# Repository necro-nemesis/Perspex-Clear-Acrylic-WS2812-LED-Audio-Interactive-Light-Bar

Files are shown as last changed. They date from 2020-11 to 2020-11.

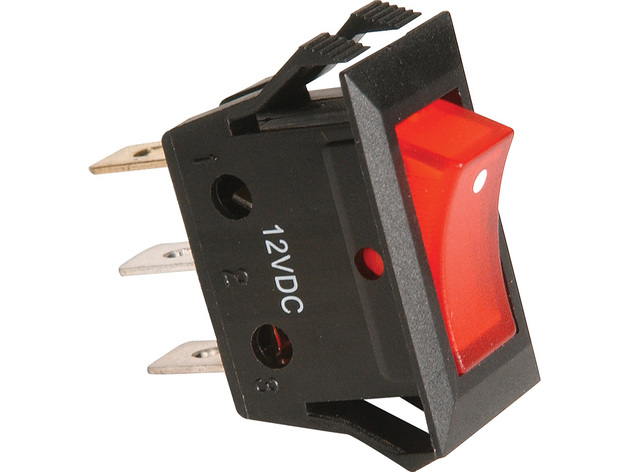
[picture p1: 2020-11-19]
images/rocker_switch.jpg

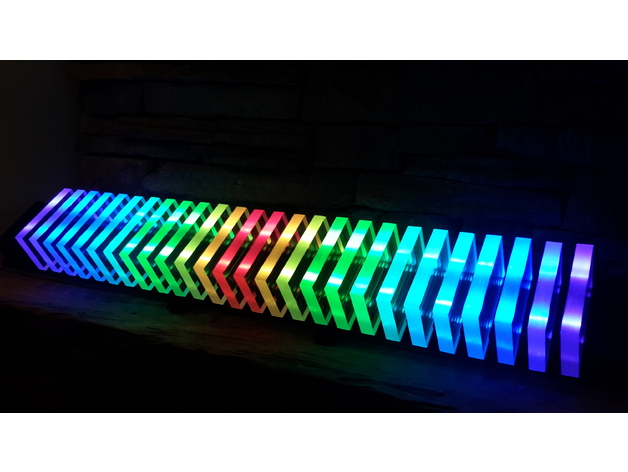
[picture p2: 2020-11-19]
images/20170909_153501.jpg

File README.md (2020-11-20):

# Perspex Clear Acrylic WS2812 LED Audio Interactive Light Bar

Click To View Video (https://youtu.be/7bf3BYers34 "Click to View Video")
### Click on image to view in action. Second sample video at https://youtu.be/d8P9hhyOXbk

# **Summary**

Perspex LED light and sound activated bar

## Material:

- 1 IKEA Moslanda 115cm picture shelf (black)
- 1 Arduino Uno
- 1 Transformer
- 2 1M 30 Pixel/M WS2812 LED strips (total of 52 LEDs required)
- 26 3/4" Thick Perspex Cast Acrylic Blocks 5" x 3"
- 1 MAX9814 Microphone Amplifier Module AGC Auto Gain Control for Arduino
- 1 470 ohm resistor
- 1 10k ohm resistor
- 1 100 uf capaitor
- 1 0.1 uf capacitor
- 1 Rocker Switch Package (L x W x H) 5.0 x 2.8 x 0.8 in. (see images folder)
- 1 Pushbutton Switch Package (L x W x H) 2.4 x 1.4 x 1.2 in. (see images folder)
- 1 48 in. x 3/4 in. x 1/16 in. Aluminum Square Tube
- 10 #8 Pan Head Sheet Metal Screws

## Printables:

- 26 Perspex Mount*
- 8 Led Strip Retainer
- 2 Center Support (minimum 2, additional supports can be added to increase stability across span 6 or 8 recommended)
- 1 Left Angular End
- 1 Right Angular End
- 1 Center Connection Junction
- 1 Arduino Screwless Hobby Top
- 1 Arduino Uno Mountable Bottom

Attention was paid to ensuring all pieces will print without support. There are fine design details to enhance FDM bridging abilities.

*Perspex is cast clear acrylic and as such will vary slightly in thickness. 3 Mount widths are provided to match to the width of your pieces for a snug fit. Before printing you must measure the thickness of each block and print the appropriate width to fit.*

Constructing this is undeniably an undertaking but I never underestimate the maker community's willingness to create astoundingly complex and wonderful things. I posted the entire circuit diagram and sketch to Autodesk Circuit but in my attempt to link it, it appears to have vanished in the move to Tinkercad. If there is enough interest I will recreate it on Tinkercad as well as discuss the assembly process. You will need an accurate means to saw finely cut slots in the IKEA shelf as this forms the basis for mounting and aligning the block retainers. There's a few skills involved but nothing insurmountable. Other than the cuts and soldering, everything else snaps,slides or screws together.





Note the sketch and light bar design uses 13 WS2812 per strip versus the 12 shown in the circuit diagram as this is a limitation of Tinkercad. I have provided a link to the light bar project in Tinkercad. Unfortunately there's problem with Tinckercad running the sketch that ran fine in simulation in previously available Autodesk Circuits and more importantly on a real Arduino Uno. The sketch compiles and runs fine on the real hardware. The signal generator was used for simulation purposes only since the site cannot simulate a MAX9814 but provides input similarly for demonstration.

https://www.tinkercad.com/things/fjsfZ70k4bY

Attribution to Robert Robert on Youtube who provided the design inspiration and original sketch which resulted in this 3d printed version of it and the modified sketch.

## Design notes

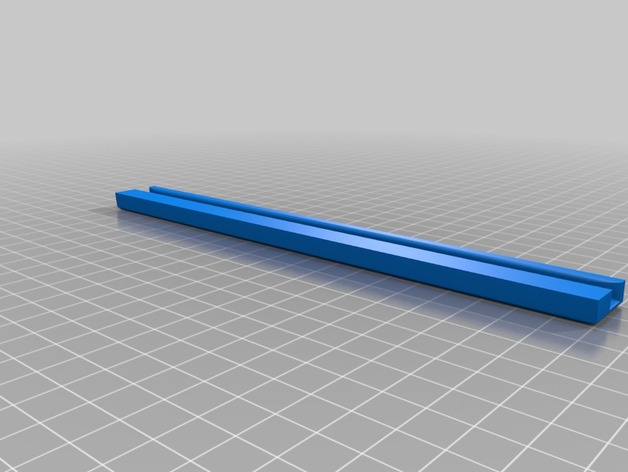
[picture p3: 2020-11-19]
images/e10bdd659c2b4d102f6c60981bce024e.png

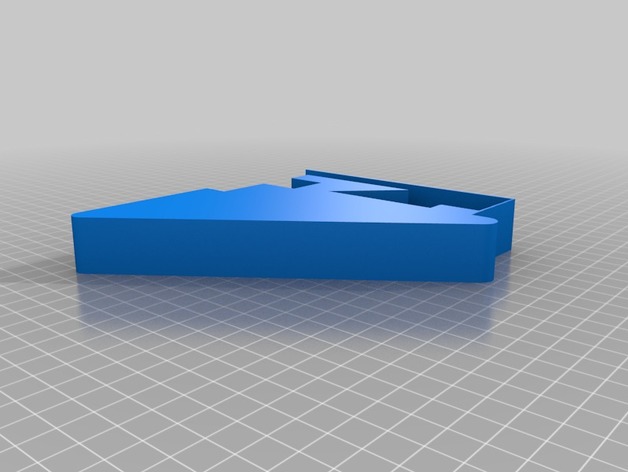
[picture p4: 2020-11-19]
images/a87dbb462eaa0ab76628953a42ff9338.png

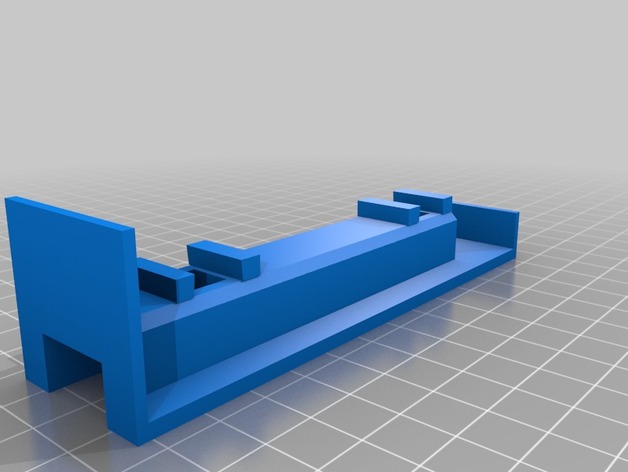
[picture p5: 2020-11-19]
images/7cbe6f95ed668d17131c1e86e14446b0.png

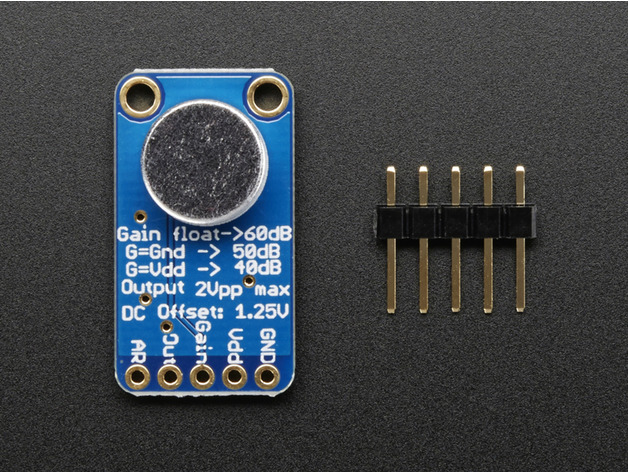
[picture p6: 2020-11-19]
images/MAX9418.jpg

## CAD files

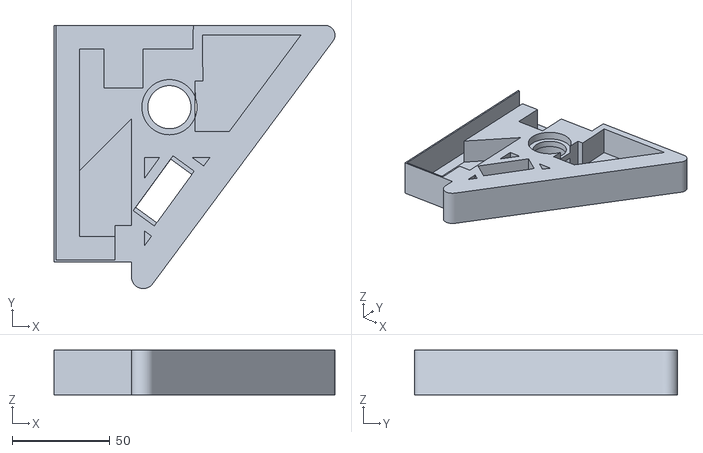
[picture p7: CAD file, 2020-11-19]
Left_Angular_End_Cap_with_Selection_Button_and_OnOff_Swtich.stl
143.7 x 134.6 x 23.0

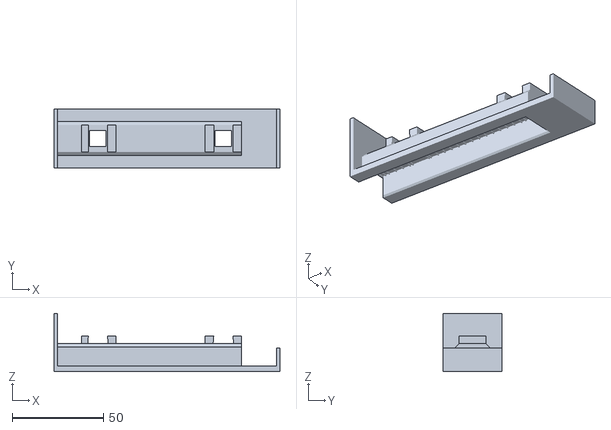
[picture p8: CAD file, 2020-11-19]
Perspex_Mount_17.6mm.stl
124.0 x 32.6 x 32.0

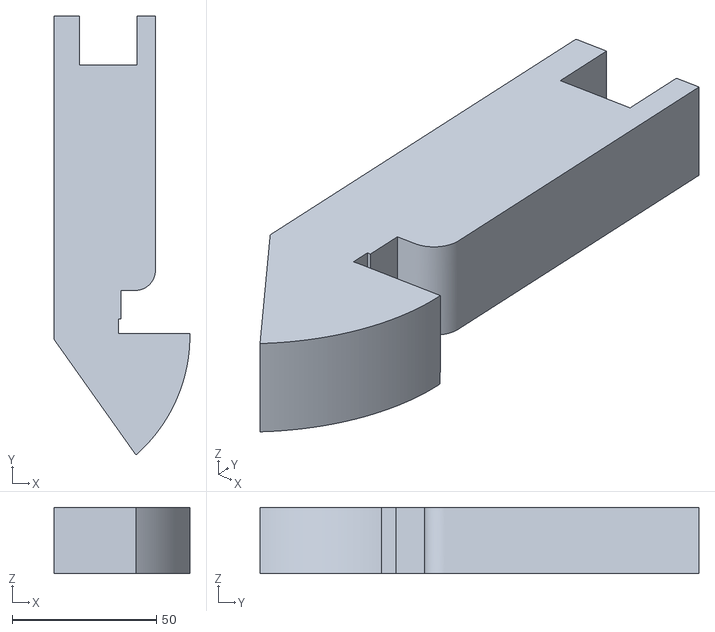
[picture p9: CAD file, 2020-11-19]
Center_Support_feet.stl
47.1 x 152.2 x 23.0

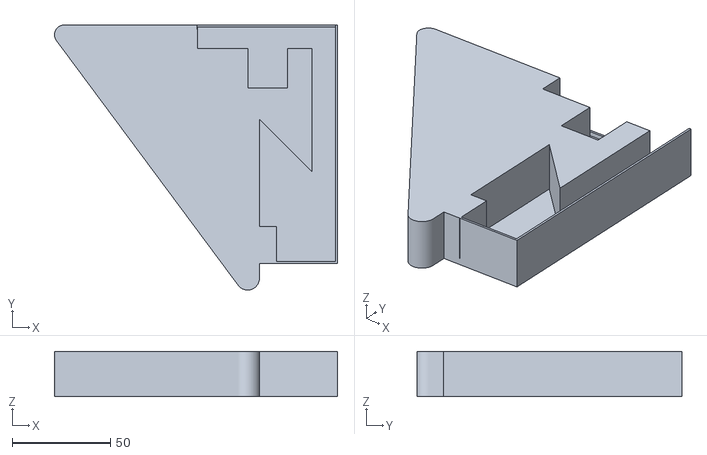
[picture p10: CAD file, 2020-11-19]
Right_Angular_End_Cap.stl
143.7 x 134.6 x 23.0

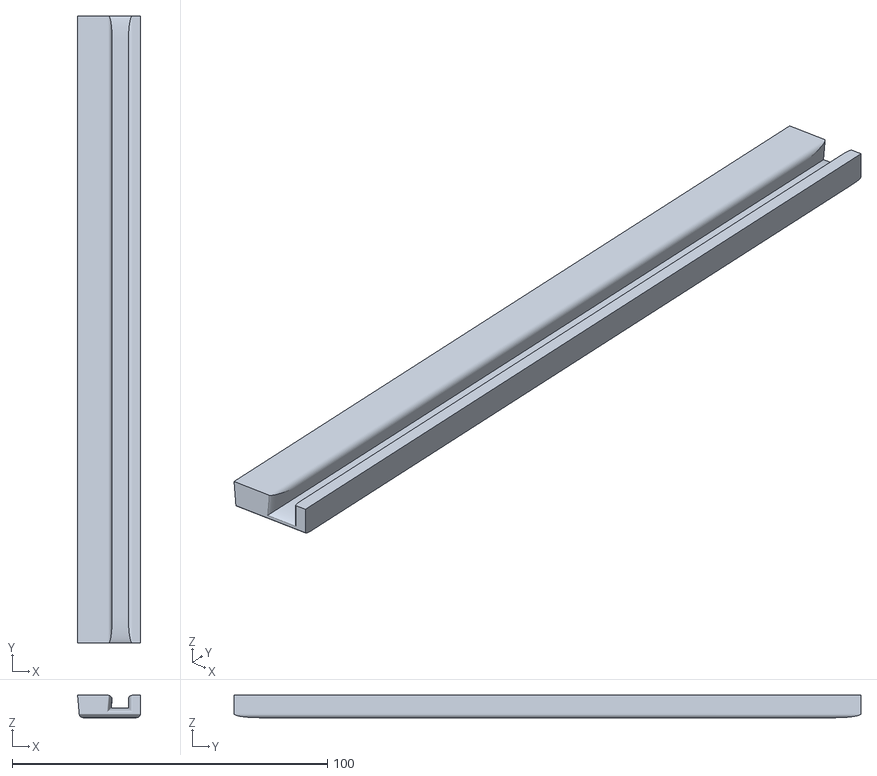
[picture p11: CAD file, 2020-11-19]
Led_Strip_Retainer_and_Interlock_Rail.stl
20.0 x 198.9 x 7.14

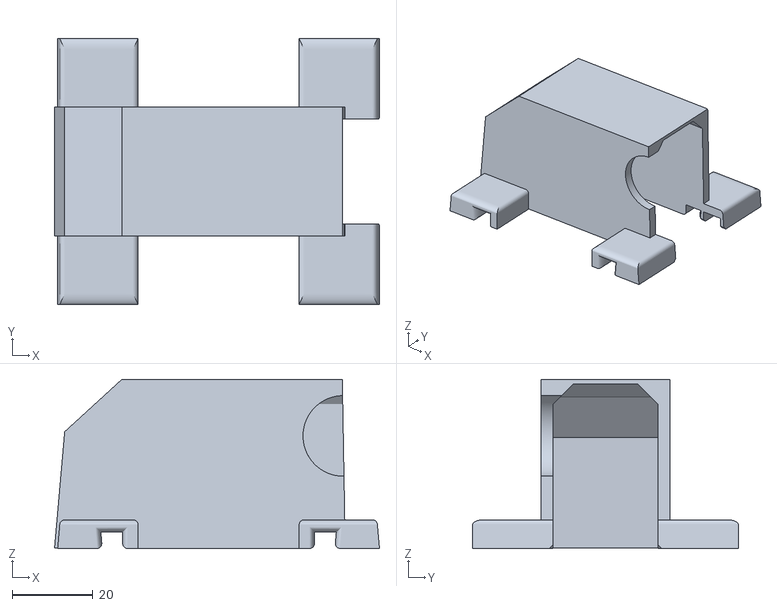
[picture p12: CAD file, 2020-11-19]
Center_Connection_Junction_Housing.stl
80.7 x 66.0 x 42.0

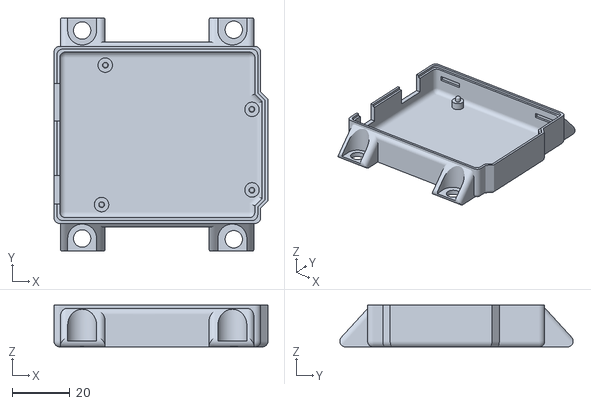
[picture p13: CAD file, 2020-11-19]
Arduino_Screwless_Mountable_Snug_Bottom.stl
74.1 x 80.8 x 14.5

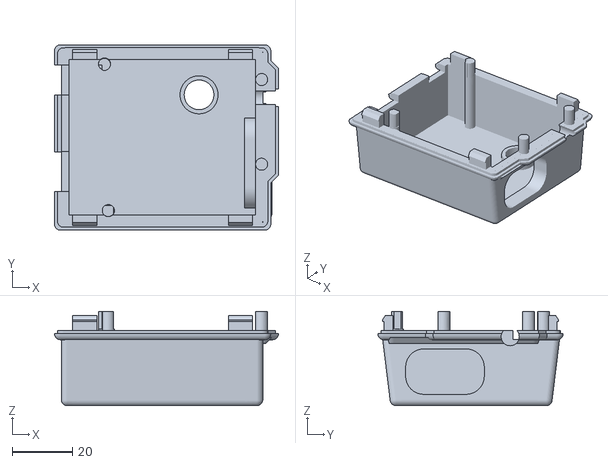
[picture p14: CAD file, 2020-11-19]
Arduino_Screwless_Hobby_Top_w_Microphone_Mount.stl
74.1 x 61.3 x 31.2

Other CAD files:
Perspex_Mount_18.25mm.stl
Perspex_Mount_17.1mm.stl

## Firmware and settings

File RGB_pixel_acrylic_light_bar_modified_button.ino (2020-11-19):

//************
//Sound Level to light show sketch for the
//autogain microphone Amplifier from Adafruit on pin AO
//plus neopixel led functions (pin 6) mapped on to different sound levels to give music to light effects
//
//*************

//lines below set variables for neopixels

#include <Adafruit_NeoPixel.h>
#include <EEPROM.h>

#define NUMBER_PIXEL 15
#define LEDPIN    6

Adafruit_NeoPixel strip = Adafruit_NeoPixel(NUMBER_PIXEL, LEDPIN, NEO_GRB + NEO_KHZ800);

//Global Variables

//Timing Block

int lng = 70;//long delay
int mod = 50;//moderate delay
int sht = 25;//short delay
int hyper = 10;//very short delay
int extreme = 5;//exceedingly short delay

//Misc Variables

uint8_t eepromAddress = 130; //Location to store last mode state during power cycle.
const int sampleWindow = 50; // Sample window width in mS (50 mS = 20Hz)
unsigned int sample;
byte toggleIdle = 1;//Level=0 toggle between idle routines.
int toggleCount = 0;
int pushButton = 2;// Assign pushbutton to input 2.
int modeSelect = 0;// Button routine selection.
boolean buttonState = 0;//
unsigned int spectrumColor[3];
unsigned int pattern [5][3];//Pixel pattern Array 5 rows, 3 RGB values.
boolean UsingBar = false; //Used by Cylon function. Set this to true If you are using the 8x1 Neopixel Bar Or you want to only use 3 leds for the scanner.
unsigned int soundLevel;
unsigned int pixelLength = 1;
unsigned int loudEffect;
unsigned int sound;


//Function Prototypes

void CylonEyeUp(uint32_t Co, uint32_t Ct, uint32_t Ctt, uint8_t Delay, int TotalPixels, int pStart);
void CylonEyeDown(uint32_t Co, uint32_t Ct, uint32_t Ctt, uint8_t Delay, int TotalPixels, int pEnd);
void Seizure(unsigned int flashRate);
void rainbowCycle(uint8_t wait, boolean direction);
void pixelFill(int pixelLength);
void turnBlack();
void colorWipe(uint32_t c, uint8_t wait);
void theaterChase(uint32_t c, uint8_t wait);
void Sparkle(byte red, byte green, byte blue, int SpeedDelay);
int Sample();
void setColor();


void setup()
{
  strip.begin();//initialises neopixels
  strip.setBrightness(255);// set brightness from 0 to max is 255
  strip.show();//clears any previous data in the strip
  pinMode (6, OUTPUT);
  pinMode (pushButton,INPUT);
  Serial.begin(9600);//set up for checking mic is working
}

void loop()
{
  // Select Mode of operation
  modeSelect = EEPROM.read(eepromAddress);
  buttonState = digitalRead(pushButton);
  if (modeSelect>3)
    {
      modeSelect=0;
      EEPROM.write(eepromAddress,modeSelect);
      for (int i = 0; i < 5; i++) {
        CylonEyeUp(strip.Color(175, 0, 0), strip.Color(25, 0, 0), strip.Color(10, 0, 0), hyper, strip.numPixels(), 0);
        //delay(hyper);
        CylonEyeDown(strip.Color(175, 0, 0), strip.Color(25, 0, 0), strip.Color(10, 0, 0), hyper, strip.numPixels(), 0);
        //delay(hyper);
      }//close Cylon;
    }
      else if (buttonState==1)
    {
      modeSelect++;
      EEPROM.write(eepromAddress,modeSelect);
      Seizure(hyper);  
    }
  Serial.print("  mode= ");
  Serial.println(modeSelect);
  switch (modeSelect){
    case 0:
   
  //Mode 0 Audio Light Show.
  //lines below are for the microphone sampling from Adafruit autogain mic
  //open void loop
  //first run the sound sampling




 
  soundLevel=Sample();

  
  //next section is a series of 12 (0-11) 'if' statements which trigger different patterns.
  //it is a combination of a traditional VU style meter fill of the strip
  // combined with randomised animated patterns to keep it interesting
  if (soundLevel > 0)
  {
   toggleIdle = ! toggleIdle;
   toggleCount = 0;
  }
  if (soundLevel == 0)
  {
    //open if 0. When there is silence a rainbow pattern runs
    if (toggleIdle == 0 && toggleCount < 3)
    {
      rainbowCycle(1,1);//from the neopixel library
      toggleCount++;
    }
    if (toggleIdle == 0 && toggleCount >=3)
    {
      rainbowCycle(4,1);
    }
    if (toggleIdle == 1)
    {
      for (int i = 0; i < 1; i++) {
        int x = random(0, 256); int y = random(0, 256); int z = random(0, 256);
        CylonEyeUp(strip.Color(x, y, z), strip.Color(x / 2, y / 2, z / 2), strip.Color(x / 4, y / 4, z / 4), sht, strip.numPixels(), 0);
        CylonEyeDown(strip.Color(x, y, z), strip.Color(x / 2, y / 2, z / 2), strip.Color(x / 4, y / 4, z / 4), sht, strip.numPixels(), 0);
        toggleIdle = ! toggleIdle;
      }
    }
  }//close if 0 statement

  if (soundLevel == 1)
  {
    //open level 1 if statement which contains 5 randomised options

    int level1Color = random(1, 7);//choose random number 1 - 5
    pixelLength = 2;

    if (level1Color == 1) //if random no 1 choses show
    {
      pattern[0][0] = 0; pattern[0][1] = 255; pattern[0][1] = 255;
      pixelFill(pixelLength);
    }//close random no. 1

    else if (level1Color == 2) //if random no 2 choses show green
    {
      pattern[0][0] = 0; pattern[0][1] = 255; pattern[0][1] = 0;
      pixelFill(pixelLength);
    }//close green

    else if (level1Color == 3) //run blue
    {
      pattern[0][0] = 0; pattern[0][1] = 0; pattern[0][1] = 255;
      pixelFill(pixelLength);
    }//close blue

    else if (level1Color == 4) //run yellow
    {
      pattern[0][0] = 255; pattern[0][1] = 255; pattern[0][1] = 0;
      pixelFill(pixelLength);
    }//close yellow

    else if (level1Color == 5) //run Cylon red
    { //Cylon loop
      for (int i = 0; i < 1; i++) {
        CylonEyeUp(strip.Color(175, 0, 0), strip.Color(25, 0, 0), strip.Color(10, 0, 0), sht, strip.numPixels(), 0);
        delay(sht);
        CylonEyeDown(strip.Color(175, 0, 0), strip.Color(25, 0, 0), strip.Color(10, 0, 0), sht, strip.numPixels(), 0);
        delay(sht);
        CylonEyeUp(strip.Color(random(0, 256), random(0, 256), random(0, 256)), strip.Color(0, 0, 0), strip.Color(0, 0, 0), hyper, strip.numPixels(), 0);
      }//close Cylon
    }//close red

    else if (level1Color == 6) //turn black
    {
      turnBlack();
    }
  }//end of if sound level 1 options


  if (soundLevel == 2)
  {
    //open level 2

    int level2Color = random(1, 7);//choose one of 5 options if sound level 2
    pixelLength = 3;
    if (level2Color == 1) //run red mix
    {

      strip.setPixelColor(0, 255, 0, 0);
      strip.setPixelColor(1, 0, 0, 255);
      strip.setPixelColor(2, 255, 0, 0);
      strip.setPixelColor(3, 0, 0, 0);
      strip.setPixelColor(4, 0, 0, 0);
      strip.setPixelColor(5, 0, 0, 0);
      strip.setPixelColor(6, 0, 0, 0);
      strip.setPixelColor(7, 0, 0, 0);
      strip.setPixelColor(8, 0, 0, 0);
      strip.setPixelColor(9, 0, 0, 0);
      strip.setPixelColor(10, 0, 0, 0);
      strip.setPixelColor(11, 0, 0, 0);
      strip.setPixelColor(12, 0, 0, 0);
      strip.setPixelColor(13, 0, 0, 0);
      strip.setPixelColor(14, 0, 0, 0);
      strip.show();
      delay(lng);
    }//close option 1 red

    else if (level2Color == 2) //run green mix
    {
      //open option 2
      pattern[0][0] = 0; pattern[0][1] = 206; pattern[0][1] = 209;
      pixelFill(pixelLength);
    }//close green

    else if (level2Color == 3) //run blue mix
    {
      //open option 3

      strip.setPixelColor(0, 0, 0, 255);
      strip.setPixelColor(1, 255, 0, 0);
      strip.setPixelColor(2, 0, 0, 255);
      strip.setPixelColor(3, 0, 0, 0);
      strip.setPixelColor(4, 0, 0, 0);
      strip.setPixelColor(5, 0, 0, 0);
      strip.setPixelColor(6, 0, 0, 0);
      strip.setPixelColor(7, 0, 0, 0);
      strip.setPixelColor(8, 0, 0, 0);
      strip.setPixelColor(9, 0, 0, 0);
      strip.setPixelColor(10, 0, 0, 0);
      strip.setPixelColor(11, 0, 0, 0);
      strip.setPixelColor(12, 0, 0, 0);
      strip.setPixelColor(13, 0, 0, 0);
      strip.setPixelColor(14, 0, 0, 0);
      strip.show();
      delay(lng);
    }//close option 3 blue

    else if (level2Color == 4) //run yellow
    {
      //open option 4
      pattern[0][0] = 255; pattern[0][1] = 255; pattern[0][1] = 0;
      pixelFill(pixelLength);
    }//close yellow

    else if (level2Color == 5)//for a bit of variation 1 in 5 of level 2 will show a pattern across whole strip:
      //open if 5 Cylon Yellow
    { //Cylon loop
      for (int i = 0; i < 2; i++) {
        CylonEyeUp(strip.Color(175, 175, 0), strip.Color(25, 25, 0), strip.Color(10, 10, 0), hyper, strip.numPixels(), strip.numPixels() / 2);
        delay(sht);
        CylonEyeDown(strip.Color(175, 175, 0), strip.Color(25, 25, 0), strip.Color(10, 10, 0), hyper, strip.numPixels(), strip.numPixels() / 2);
        delay(sht);
      }//close Cylon
    }//close of option 5

    else if (level2Color == 6) //turn black
    {
      turnBlack();
    }//close option 6
  }//close level 2

  if (soundLevel == 3)
  {
    //open if sound level 3
    int level3Color = random(1, 7);
    pixelLength = 4;
    if (level3Color == 1) //run red
    {
      //open option 1

      strip.setPixelColor(0, 255, 0, 0);
      strip.setPixelColor(1, 0, 255, 0);
      strip.setPixelColor(2, 255, 0, 0);
      strip.setPixelColor(3, 0, 255, 0);
      strip.setPixelColor(4, 0, 0, 0);
      strip.setPixelColor(5, 0, 0, 0);
      strip.setPixelColor(6, 0, 0, 0);
      strip.setPixelColor(7, 0, 0, 0);
      strip.setPixelColor(8, 0, 0, 0);
      strip.setPixelColor(9, 0, 0, 0);
      strip.setPixelColor(10, 0, 0, 0);
      strip.setPixelColor(11, 0, 0, 0);
      strip.setPixelColor(12, 0, 0, 0);
      strip.setPixelColor(13, 0, 0, 0);
      strip.setPixelColor(14, 0, 0, 0);
      strip.show();
      delay(lng);
    }//close option 1 red

    else if (level3Color == 2) //run green
    {
      //open option 2

      strip.setPixelColor(0, 245, 116, 97);
      strip.setPixelColor(1, 169, 221, 20);
      strip.setPixelColor(2, 245, 116, 97);
      strip.setPixelColor(3, 169, 221, 20);
      strip.setPixelColor(4, 0, 0, 0);
      strip.setPixelColor(5, 0, 0, 0);
      strip.setPixelColor(6, 0, 0, 0);
      strip.setPixelColor(7, 0, 0, 0);
      strip.setPixelColor(8, 0, 0, 0);
      strip.setPixelColor(9, 0, 0, 0);
      strip.setPixelColor(10, 0, 0, 0);
      strip.setPixelColor(11, 0, 0, 0);
      strip.setPixelColor(12, 0, 0, 0);
      strip.setPixelColor(13, 0, 0, 0);
      strip.setPixelColor(14, 0, 0, 0);
      strip.show();
      delay(lng);
    }//close option 2green

    else if (level3Color == 3) //run blue
    {
      //open option 3

      strip.setPixelColor(0, 169, 221, 199);
      strip.setPixelColor(1, 245, 116, 97);
      strip.setPixelColor(2, 169, 221, 199);
      strip.setPixelColor(3,  245, 116, 97);
      strip.setPixelColor(4, 0, 0, 0);
      strip.setPixelColor(5, 0, 0, 0);
      strip.setPixelColor(6, 0, 0, 0);
      strip.setPixelColor(7, 0, 0, 0);
      strip.setPixelColor(8, 0, 0, 0);
      strip.setPixelColor(9, 0, 0, 0);
      strip.setPixelColor(10, 0, 0, 0);
      strip.setPixelColor(11, 0, 0, 0);
      strip.setPixelColor(12, 0, 0, 0);
      strip.setPixelColor(13, 0, 0, 0);
      strip.setPixelColor(14, 0, 0, 0);
      strip.show();
      delay(lng);
    }//close option 3 blue

    else if (level3Color == 4) //run yellow
    {
      //open option 4
      pattern[0][0] = 255; pattern[0][1] = 255; pattern[0][1] = 0;
      pixelFill(pixelLength);
    }//close option 4 yellow

    else if (level3Color == 5)
    {
      //open option 5
      strip.setPixelColor(0, 255, 255, 255);
      strip.setPixelColor(1, 255, 105, 180);
      strip.setPixelColor(2, 255, 255, 255);
      strip.setPixelColor(3, 255, 105, 180);
      strip.setPixelColor(4, 255, 255, 255);
      strip.setPixelColor(5, 255, 105, 180);
      strip.setPixelColor(6, 255, 255, 255);
      strip.setPixelColor(7, 255, 105, 180);
      strip.setPixelColor(8, 255, 255, 255);
      strip.setPixelColor(9, 255, 105, 180);
      strip.setPixelColor(10, 255, 255, 255);
      strip.setPixelColor(11, 255, 105, 180);
      strip.setPixelColor(12, 255, 255, 255);
      strip.setPixelColor(13, 255, 105, 180);
      strip.setPixelColor(14, 255, 255, 255);
      strip.show();
      delay(sht);
    }//close of option 5
    else if (level3Color == 6) //turn black
    {
      turnBlack();
    }//close option 6
  }//close level 3


  if (soundLevel == 4)
  {
    //open if sound level 4
    int level4Color = random(1, 7);
    pixelLength = 5;
    if (level4Color == 1) //run red
    {
      //open option 1

      strip.setPixelColor(0, 255, 0, 0);
      strip.setPixelColor(1, 0, 0, 255);
      strip.setPixelColor(2, 255, 0, 0);
      strip.setPixelColor(3, 0, 0, 255);
      strip.setPixelColor(4, 255, 0, 0);
      strip.setPixelColor(5, 0, 0, 0);
      strip.setPixelColor(6, 0, 0, 0);
      strip.setPixelColor(7, 0, 0, 0);
      strip.setPixelColor(8, 0, 0, 0);
      strip.setPixelColor(9, 0, 0, 0);
      strip.setPixelColor(10, 0, 0, 0);
      strip.setPixelColor(11, 0, 0, 0);
      strip.setPixelColor(12, 0, 0, 0);
      strip.setPixelColor(13, 0, 0, 0);
      strip.setPixelColor(14, 0, 0, 0);
      strip.show();
      delay(lng);
    }//close red

    else if (level4Color == 2) //run green
    {
      //open option 2
      pattern[0][0] = 0; pattern[0][1] = 255; pattern[0][1] = 0;
      pixelFill(pixelLength);
    }//close green

    else if (level4Color == 3) //run blue
    {
      //open option 3
      pattern[0][0] = 0; pattern[0][1] = 0; pattern[0][1] = 255;
      pixelFill(pixelLength);
    }//close blue

    else if (level4Color == 4) //run yellow
    {
      //open option 4
      pattern[0][0] = 255; pattern[0][1] = 255; pattern[0][1] = 0;
      pixelFill(pixelLength);
    }//close yellow

    else if (level4Color == 5)
    {
      //Cylon loop
      for (int i = 0; i < 2; i++) {
        CylonEyeUp(strip.Color(0, 175, 175), strip.Color(0, 25, 25), strip.Color(0, 25, 25), hyper, strip.numPixels(), 0);
        delay(sht);
        CylonEyeDown(strip.Color(175, 0, 175), strip.Color(25, 0, 25), strip.Color(10, 0, 10), hyper, strip.numPixels(), 0);
        delay(20);
      }//close Cylon
    }//close option 5

  }//close if sound level 4

  else if (soundLevel == 5)
  {
    //open if sound level 5


    int level5Color = random(1, 7);
    pixelLength = 6;
    if (level5Color == 1) //run red
    {
      //open option 1
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
}//close void loop()


//neopixel functions below



void colorWipe(uint32_t c, uint8_t wait)
{
  //open colorwipe
  for (uint16_t i = 0; i < strip.numPixels(); i++)
  {
    strip.setPixelColor(i, c);
    strip.show();
    delay(wait);
  }
}//close colorWipe function

void theaterChase(uint32_t c, uint8_t wait)
{
  //open theaterchase function
  for (int j = 0; j < 4; j++) //do 4 cycles of chasing
  {
    for (int q = 0; q < 3; q++)
    {
      for (int i = 0; i < strip.numPixels(); i = i + 3)
      {
        strip.setPixelColor(i + q, c);  //turn every third pixel on
      }
      strip.show();

      delay(wait);

      for (int i = 0; i < strip.numPixels(); i = i + 3)
      {
        strip.setPixelColor(i + q, 0);      //turn every third pixel off
      }
    }
  }
}//close theater chase function

void rainbowCycle(uint8_t wait, boolean direction)  //open rainbow function
{
  uint16_t i, j;

  if (direction==1){

  for (j = 0; j < 256; j++) // 1 cycles of all colors on wheel
  {
    for (i = 0; i < strip.numPixels(); i++)
    {
      strip.setPixelColor(i, Wheel(((i * 256 / strip.numPixels()) + j) & 255));
    }
    strip.show();
    buttonState = digitalRead(pushButton);
    if (buttonState==1) {
      break;
      }
    delay(wait);
  }
  }
  else{
  
  for (j = 256; j > 0; j--) // 1 cycles of all colors on wheel
  {
    for (i = 0; i < strip.numPixels(); i++)
    {
      strip.setPixelColor(i, Wheel(((i * 256 / strip.numPixels()) + j) & 255));
    }
    strip.show();
    buttonState = digitalRead(pushButton);
    if (buttonState==1) {
      break;
      }
    delay(wait);
  }  
  }
}//close rainbow function


//you need to included the code below for the neopixel functions that use the 'wheel' code:
uint32_t Wheel(byte WheelPos)
{
  WheelPos = 255 - WheelPos;
  if (WheelPos < 85)
  {
    return strip.Color(255 - WheelPos * 3, 0, WheelPos * 3);
  }
  if (WheelPos < 170)
  {
    WheelPos -= 85;
    return strip.Color(0, WheelPos * 3, 255 - WheelPos * 3);
  }
  WheelPos -= 170;
  return strip.Color(WheelPos * 3, 255 - WheelPos * 3, 0);
}


// Sparkle Function

void Sparkle(byte red, byte green, byte blue, int SpeedDelay) {
  int Pixel = random(strip.numPixels());
  strip.setPixelColor(Pixel, red, green, blue);
  strip.show();
  delay(SpeedDelay);
  strip.setPixelColor(Pixel, 0, 0, 0);
}

// Custom Functions below

//Color in the pixels starting from pixle 0

void pixelFill(int pixelLength)
{
  for (int i = 0; i < pixelLength; i++)
  {
    strip.setPixelColor(i, pattern[0][0], pattern[0][1], pattern[0][2]);
    delay(hyper);
    strip.show();
  }
  for (int x = pixelLength; x <= strip.numPixels(); x++)
  {
    strip.setPixelColor(x, 0, 0 , 0);
  }
  strip.show();
}

void turnBlack()
{
  for (int x = 0; x <= strip.numPixels(); x++)
  {
    strip.setPixelColor(x, 0, 0 , 0);
    delay(sht);
    strip.show();
  }
}

//Cylon Function

void CylonEyeUp(uint32_t Co, uint32_t Ct, uint32_t Ctt, uint8_t Delay, int TotalPixels, int pStart) {
  for (int i = pStart; i < TotalPixels; i++) {
    if (!UsingBar) {
      strip.setPixelColor(i + 2, Ctt);  //Third Dot Color
    }
    strip.setPixelColor(i + 1, Ct); //Second Dot Color
    strip.setPixelColor(i, Co);     //Center Dot Color
    strip.setPixelColor(i - 1, Ct); //Second Dot Color
    if (!UsingBar) {
      strip.setPixelColor(i - 2, Ctt);  //Third Dot Color
    }

    if (!UsingBar) {
      strip.setPixelColor(i - 3, strip.Color(0, 0, 0)); //Clears the dots after the 3rd color
    } else {
      strip.setPixelColor(i - 2, strip.Color(0, 0, 0)); //Clears the dots after the 2rd color
    }
    strip.show();
    //Serial.println(i); //Used For pixel Count Debugging
    delay(Delay);
  }
}
void CylonEyeDown(uint32_t Co, uint32_t Ct, uint32_t Ctt, uint8_t Delay, int TotalPixels, int pEnd) {
  for (int i = TotalPixels - 1; i > pEnd; i--) {
    if (!UsingBar) {
      strip.setPixelColor(i - 2, Ctt);  //Third Dot Color
    }
    strip.setPixelColor(i - 1, Ct); //Second Dot Color
    strip.setPixelColor(i, Co);    //Center Dot Color
    strip.setPixelColor(i + 1, Ct); //Second Dot Color
    if (!UsingBar) {
      strip.setPixelColor(i + 2, Ctt);  //Third Dot Color
    }

    if (!UsingBar) {
      strip.setPixelColor(i + 3, strip.Color(0, 0, 0)); //Clears the dots after the 3rd color
    } else {
      strip.setPixelColor(i + 2, strip.Color(0, 0, 0)); //Clears the dots after the 2rd color
    }
    strip.show();
    //Serial.println(i); //Used For pixel Count Debugging
    delay(Delay);
  }
}

//Seizure Function

void Seizure(unsigned int flashRate)
{  unsigned int sectorSize = strip.numPixels()/3;
    for (int i = 0; i <= 6; i++)
  {
    for (int j=0; j<=sectorSize; j++)
    {
    strip.setPixelColor(j, 255,255,255);
    strip.setPixelColor(j+sectorSize, 0, 0 ,0);
    strip.setPixelColor(j+2*sectorSize, 255,255,255);
    strip.show();
    delay(flashRate);
    }
    for (int k=0; k<=sectorSize; k++)
    {
    strip.setPixelColor(k, 0,0,0);
    strip.setPixelColor(k+sectorSize, 255,255,255);
    strip.setPixelColor(k+2*sectorSize, 0,0,0);
    strip.show();
    delay(flashRate);
  }
}
}
    ////Full color spectrum transition code !!!WARNING Pixel Killer Code if misused!!!
    //  This code will run all pixels through the entire spectrum simultaneously but at delays less than 5ms proved pixel lethal in time!!!

    void setColor(){
      // Start off with red.
        spectrumColor[0] = 255;
        spectrumColor[1] = 0;
        spectrumColor[2] = 0;
    
        // Choose the Colors to increment and decrement.
        for (int decColor = 0; decColor < 3; decColor += 1) {
          int incColor = decColor == 2 ? 0 : decColor + 1;
    
          // cross-fade the two Colors.
          for(int i = 0; i < 255; i += 1) {
            spectrumColor[decColor] -= 1;
            spectrumColor[incColor] += 1;
            for (int x = 0; x < strip.numPixels(); x++){
            strip.setPixelColor(x, spectrumColor[0], spectrumColor[1],spectrumColor[2]);
            }
            strip.show();
            buttonState = digitalRead(pushButton);
                if (buttonState==1) {
                break;
                }
            delay(100);
          }
        }
      }
    ////end of color transition code !!!End of Pixel Killer Code!!!

int Sample(){
  // collect data for 50 mS
  unsigned long startMillis = millis(); // Start of sample window
  unsigned int peakToPeak = 0;   // peak-to-peak level
  unsigned int signalMax = 0;
  unsigned int signalMin = 1024;
  unsigned int minSampleSum = 0;
  unsigned int minSampleAverage = 1;
  unsigned int sampleNoise = 0;
  while (millis() - startMillis < sampleWindow)
  {
    //open while loop
    sample = analogRead(0);
    if (sample < 1024)  // toss out spurious readings
    {
      //open 1st if loop in while
      if (sample > signalMax)
      {
        //open 2nd if
        signalMax = sample;  // save just the max levels
      }//close 2nd if
      else if (sample < signalMin)
      {
        signalMin = (minSampleSum + sample) / minSampleAverage;
        minSampleSum = minSampleSum + sample;
        minSampleAverage++;
        // average the min levels to establish baseline noise.
      }//close 3rd if
    }//close 1st if
  }//close while loop
  peakToPeak = signalMax - signalMin;  // max - min = peak-peak amplitude
  double volts = (peakToPeak * 3.3) / 1024;  // convert to volts
  
  //section below maps the signal from the microphone on to 12 options for LED effects

  int sound = constrain((volts * 100), 30, 155);//generate voltage value and constrain results.
  int soundValue = map(sound, 30, 155, 0, 11);// map constrained values range 0 to 11.
  
  
  Serial.print("The level is: ");
  Serial.print("volts= ");
  Serial.print (sound);
  Serial.print ("  level= ");
  Serial.println(soundValue);
  //for debugging

  return soundValue;
  }

//end

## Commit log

2020-11-19 Drawing files and README.md
    [Arduino_Screwless_Hobby_Top_w_Microphone_Mount.stl, Arduino_Screwless_Mountable_Snug_Bottom.stl, Center_Connection_Junction_Housing.stl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]
2020-11-19 add circuit diagram
